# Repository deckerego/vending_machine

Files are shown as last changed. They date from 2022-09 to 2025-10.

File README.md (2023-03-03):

# The Life-Sized Vending Machine

A seven-foot tall Halloween vending machine, inspired by the [Exploding Kittens merch booth](https://makezine.com/article/maker-news/exploding-kittens-vending-machine/).

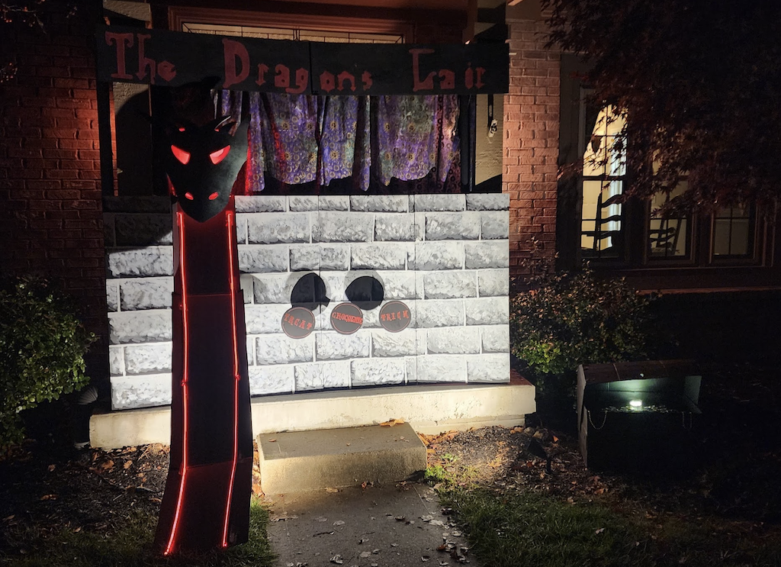
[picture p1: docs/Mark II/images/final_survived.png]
The Mark II Vending machine at night


Mark II Images: [docs/Mark II](docs/Mark%20II/README.md)

Mark II Sketches: [docs/Mark II](docs/Mark%20II/Sketches%20and%20Notes.pdf)

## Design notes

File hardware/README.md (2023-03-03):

# 3D Printed Hardware & Mounts

3D printed hardware used to construct things. Also [available on Printibles](https://www.printables.com/model/414187-dowel-rod-guides-and-mounts)

Included the original Blender source if things need to be scaled.

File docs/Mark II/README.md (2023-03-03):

# Halloween Vending Machine

## Mark II

A brief outline:

Painting the front panels 

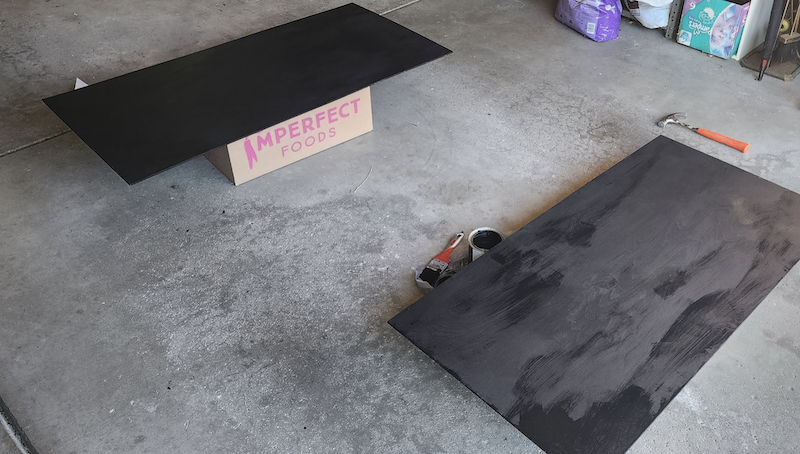
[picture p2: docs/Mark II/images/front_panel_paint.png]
Plywood being painted black for the front of the vending machine


Marking and placing the dowel rod mounts 

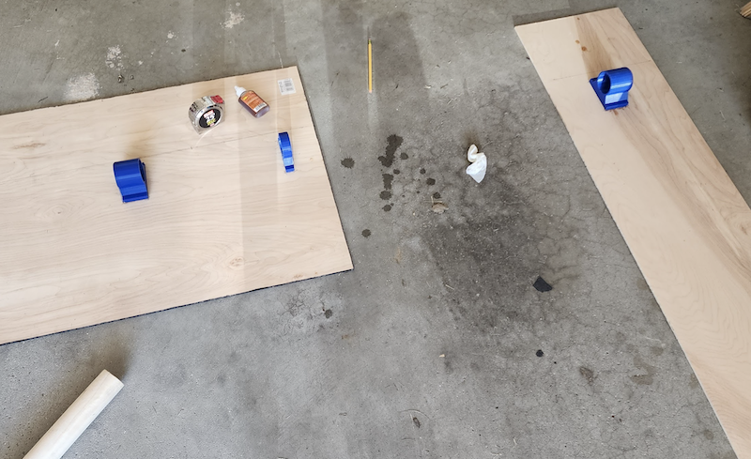
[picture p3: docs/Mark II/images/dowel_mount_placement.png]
Plastic anchors used to hold dowel rolds in place being measured on the back of plywood


Gluing & screwing on the dowel rod mounts 

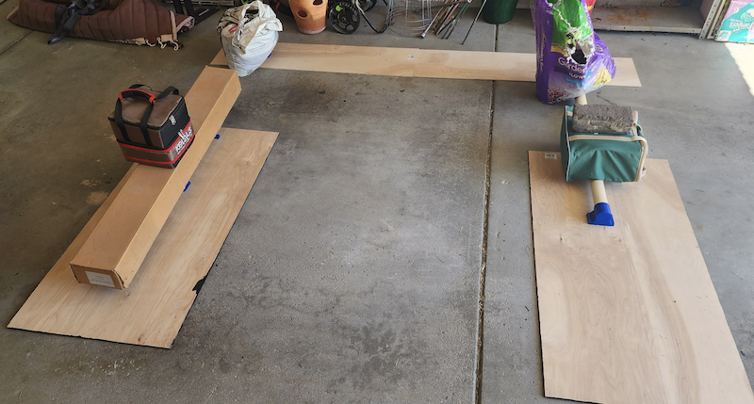
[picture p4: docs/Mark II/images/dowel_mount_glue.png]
Glue setting on plastic dowel rod mounts


Adding hinges to the front panels to make them a larger, foldable structure 

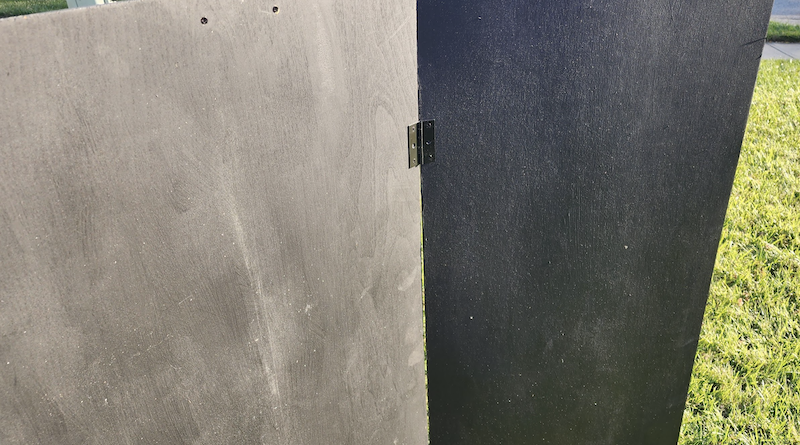
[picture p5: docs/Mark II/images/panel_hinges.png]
Close-up of hinges holding together two plywood sheets
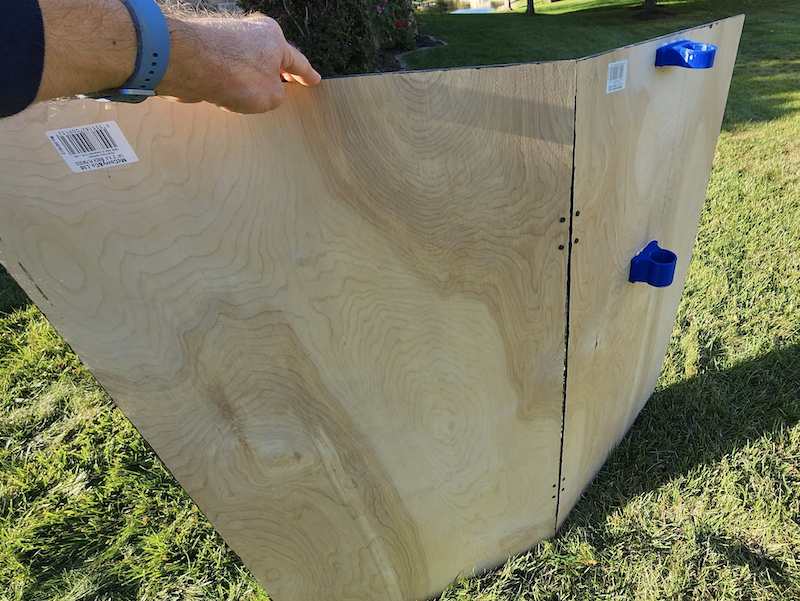
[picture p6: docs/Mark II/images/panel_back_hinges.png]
Opposite side of plywood showing hinges mounting two pieces together
 

Test assembly of the panels, dowel rods, and overhead sign 

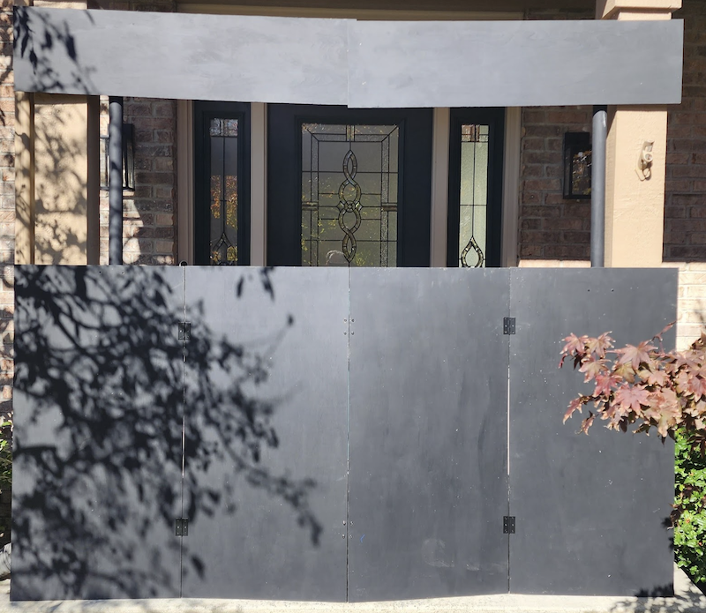
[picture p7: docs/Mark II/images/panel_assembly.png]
The first prototype of the vending machine with working hinges and mounts


1. Paint details & designs on the front panels & signs 

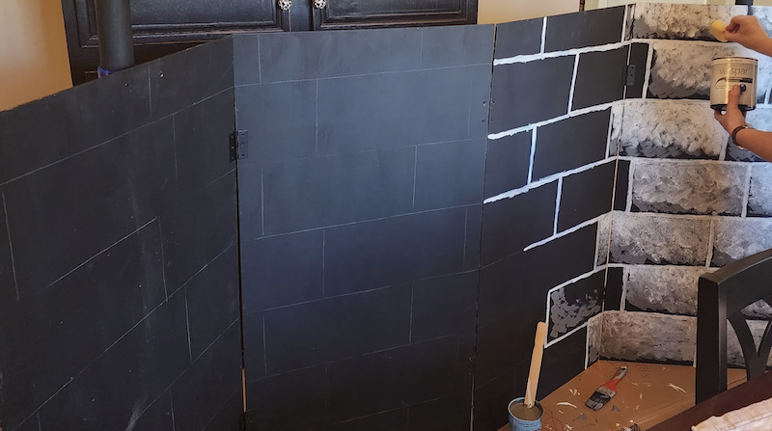
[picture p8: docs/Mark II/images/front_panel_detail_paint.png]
Sponge painting a brick pattern on the front panel


1. Paint buttons and text for buttons 

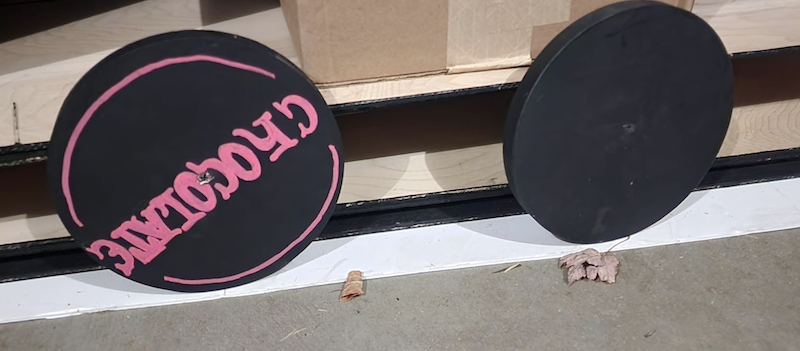
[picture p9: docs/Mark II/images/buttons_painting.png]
Big wooden buttons, one of which says "chocolate."


1. Template, cut, curve, and heat mold the dragon head out of EVA foam 

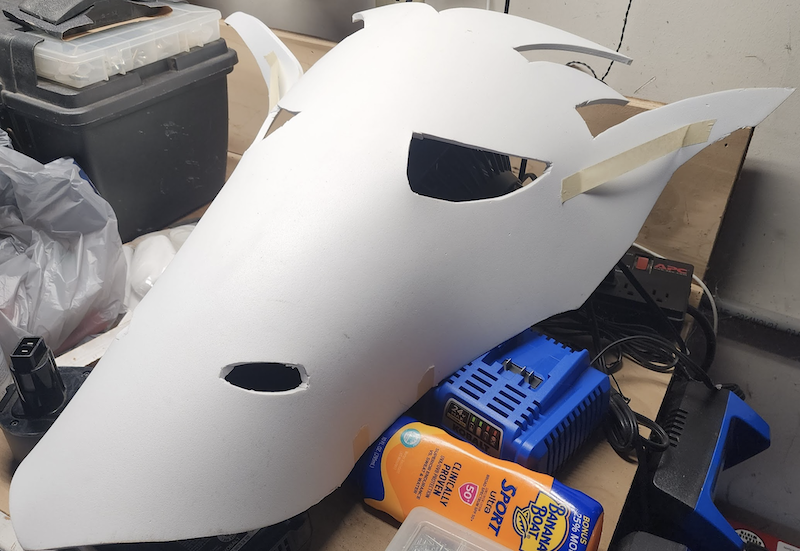
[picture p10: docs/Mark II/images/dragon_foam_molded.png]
A two-dimensional dragon's head made out of foam, held into a shape with tape


1. Prime and paint the dragon's head 

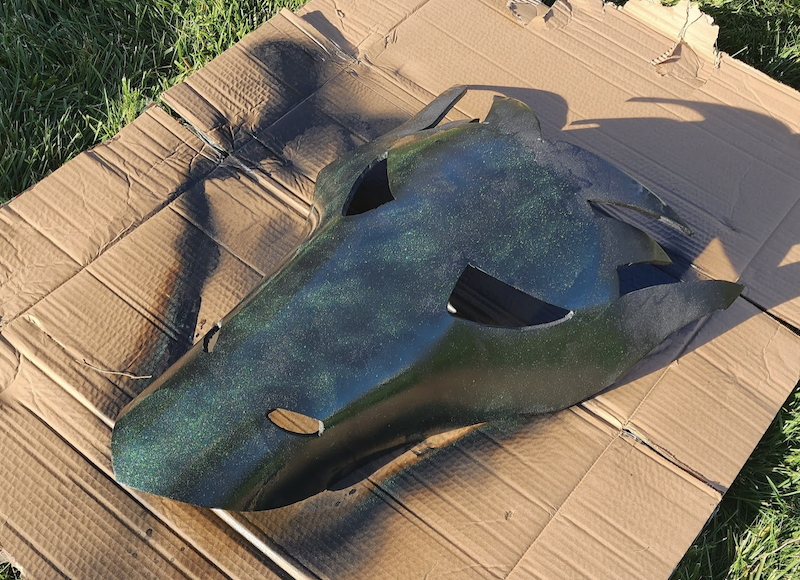
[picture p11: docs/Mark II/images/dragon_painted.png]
The dragon's head from the earlier step spray-painted a glossy green


1. Code an Adafruit Express as an LED backlight for the dragon's head 

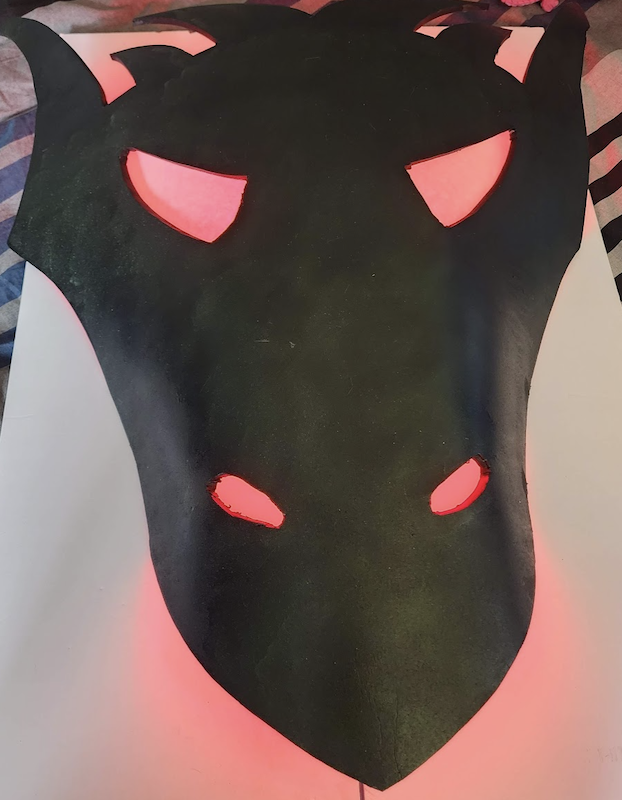
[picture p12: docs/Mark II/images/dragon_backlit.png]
A bright red backlight shines behind the dragon's head


1. Solder jumper wires to the LED strips for the candy ramp 

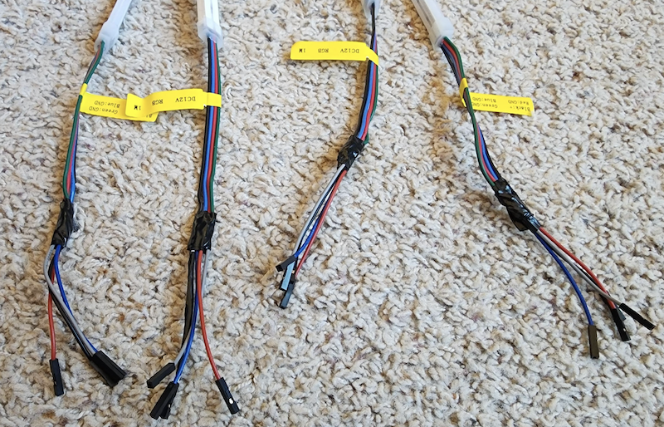
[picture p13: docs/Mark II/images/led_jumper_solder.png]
Jumper wires freshly soldered onto LED ropes


1. Connect buttons, a battery pack, and LED strips to an Arduino. Code to make a fade effect for lighting. 

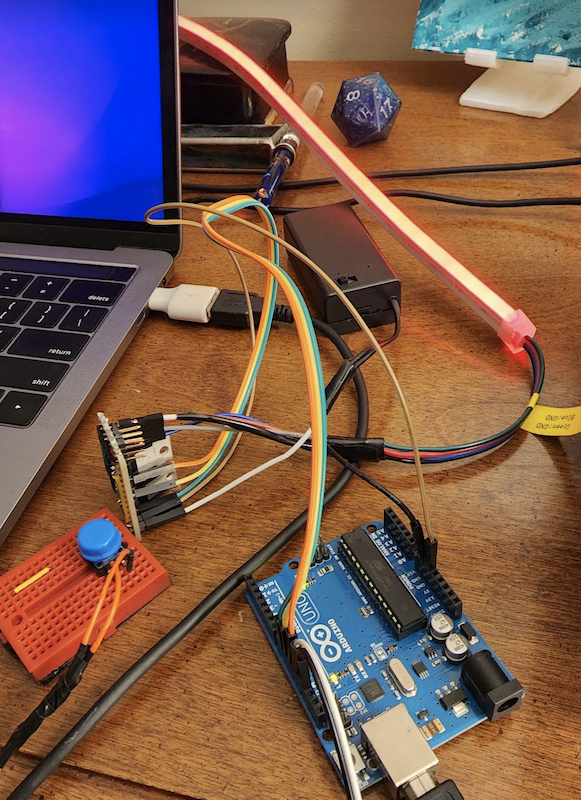
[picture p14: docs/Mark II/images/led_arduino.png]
A mess of wires leading to an Arduino, code showing on a nearby laptop


1. Pull the LED strips through the candy ramp, adhere to the sides. Attach Arduino and battery pack underneath the ramp 

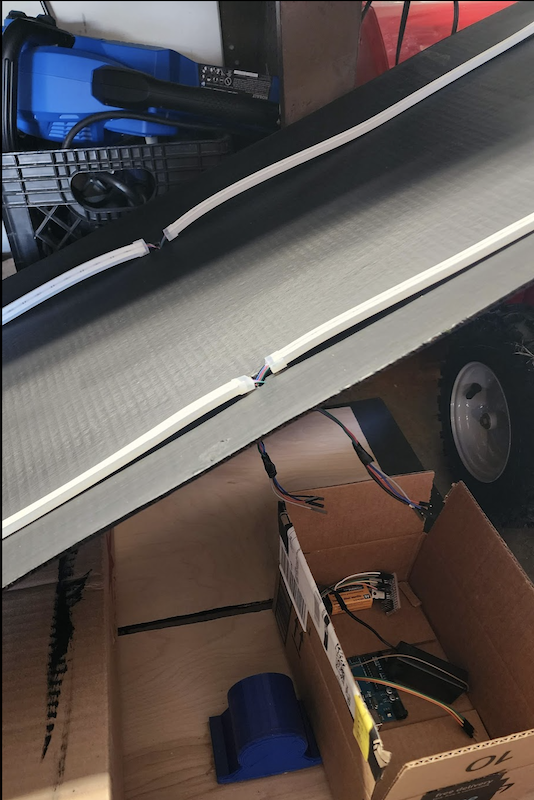
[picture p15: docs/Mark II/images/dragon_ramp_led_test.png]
A prototype candy ramp with LED strips on either side, wires leading to the Arduino assembly


1. Drill holes & mount the button guides within the front panels 

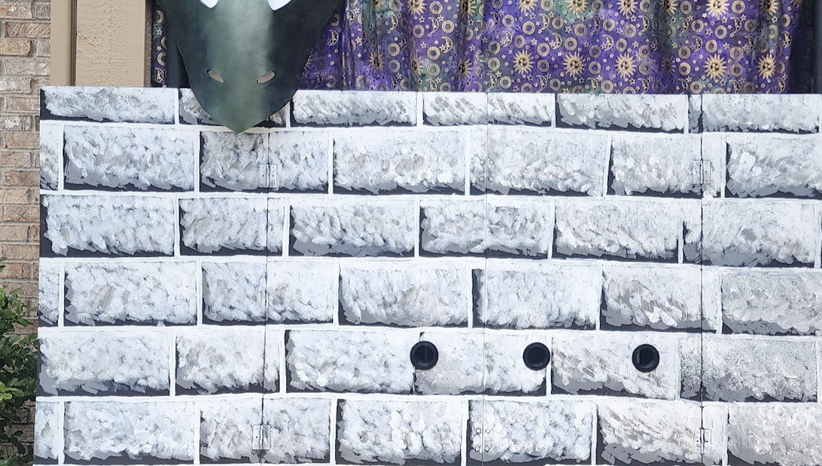
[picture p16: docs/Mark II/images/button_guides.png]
Plastic guides for the button dowel rods inserted into the vending machine panels


1. Anchor entire assembly to front porch 

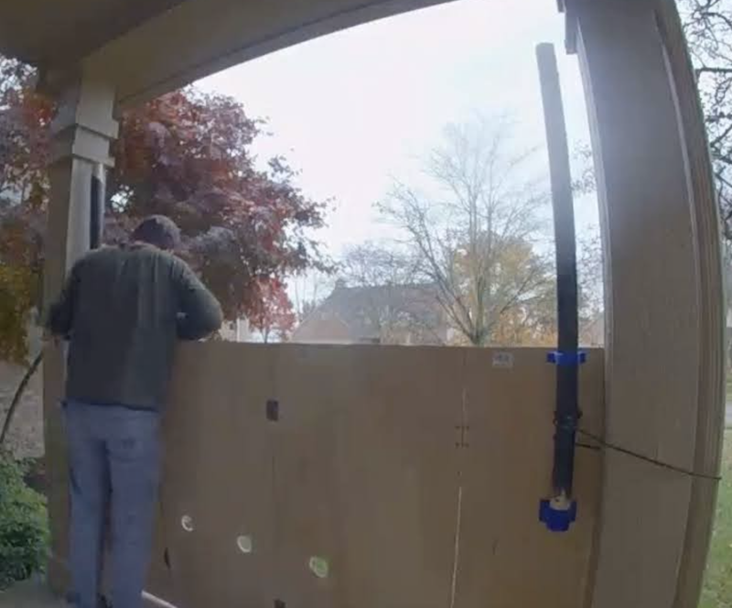
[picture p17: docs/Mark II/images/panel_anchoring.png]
Vending machine being anchored to a front porch using bungee cords


1. Anchor dragon head, candy ramp, insert buttons, add lighting accents 

The whole vending machine assembled with a candy ramp coming from a dragon head, and huge buttons labelled "trick," "treat," and "chocolate"

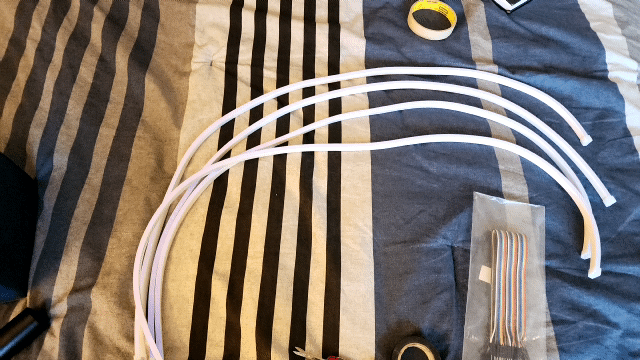
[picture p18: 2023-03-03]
docs/Mark II/images/led_strip_anim.gif

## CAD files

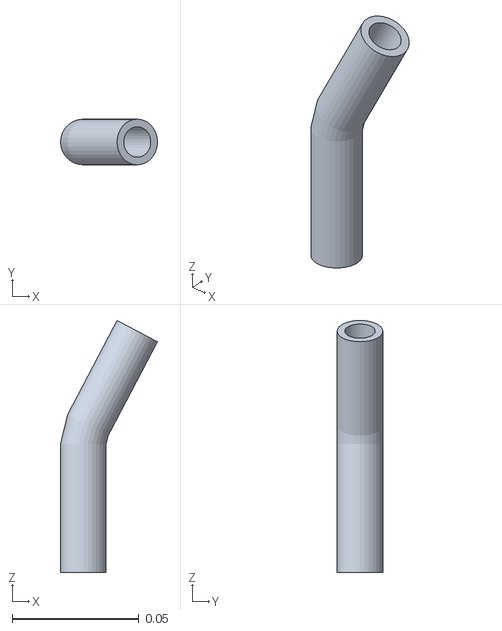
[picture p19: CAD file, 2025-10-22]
hardware/Bend Joint.stl
0.0383 x 0.0181 x 0.0995

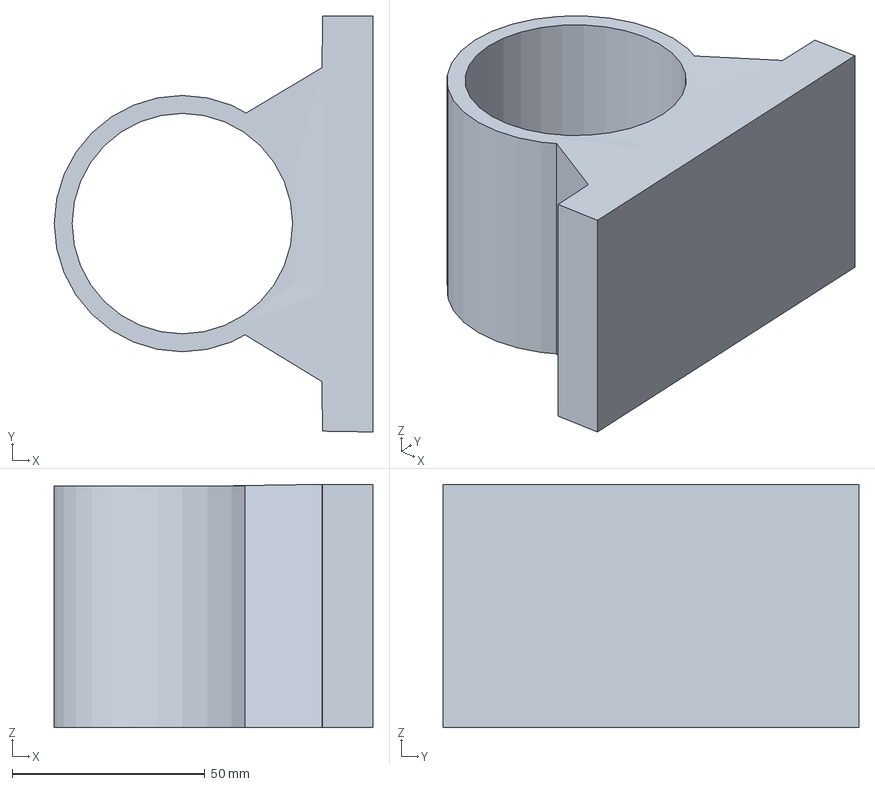
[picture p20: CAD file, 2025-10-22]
hardware/Dowel Rod Guide.3mf
82.6 x 107.9 x 63.1 mm

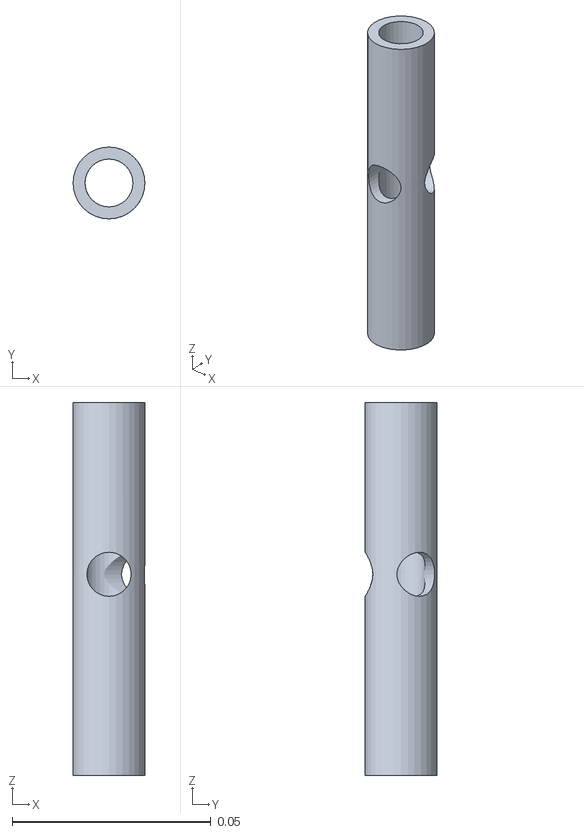
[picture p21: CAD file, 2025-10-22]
hardware/Straight Joint.stl
0.0181 x 0.0181 x 0.0938

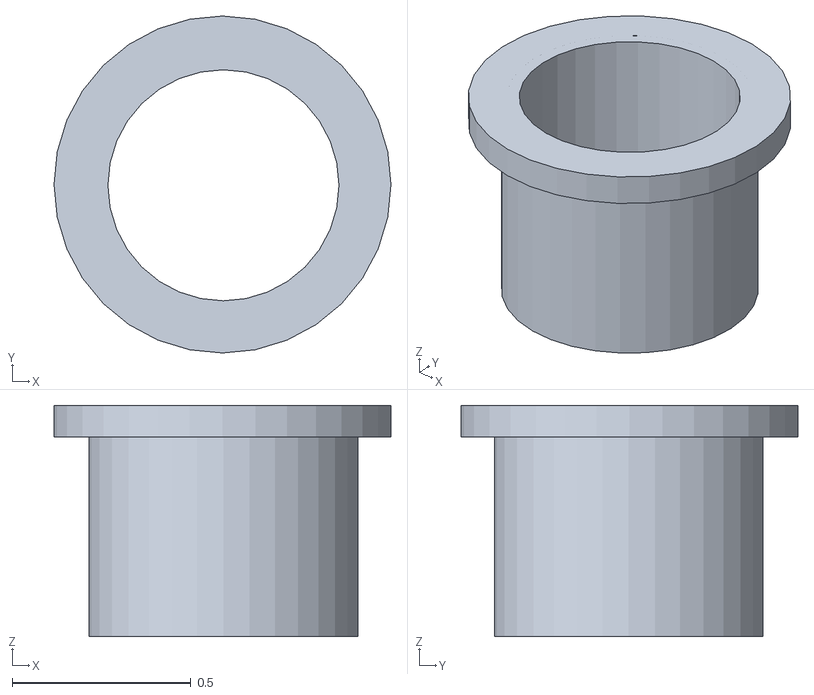
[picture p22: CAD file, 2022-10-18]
hardware/Button Guide.stl
0.944 x 0.944 x 0.648

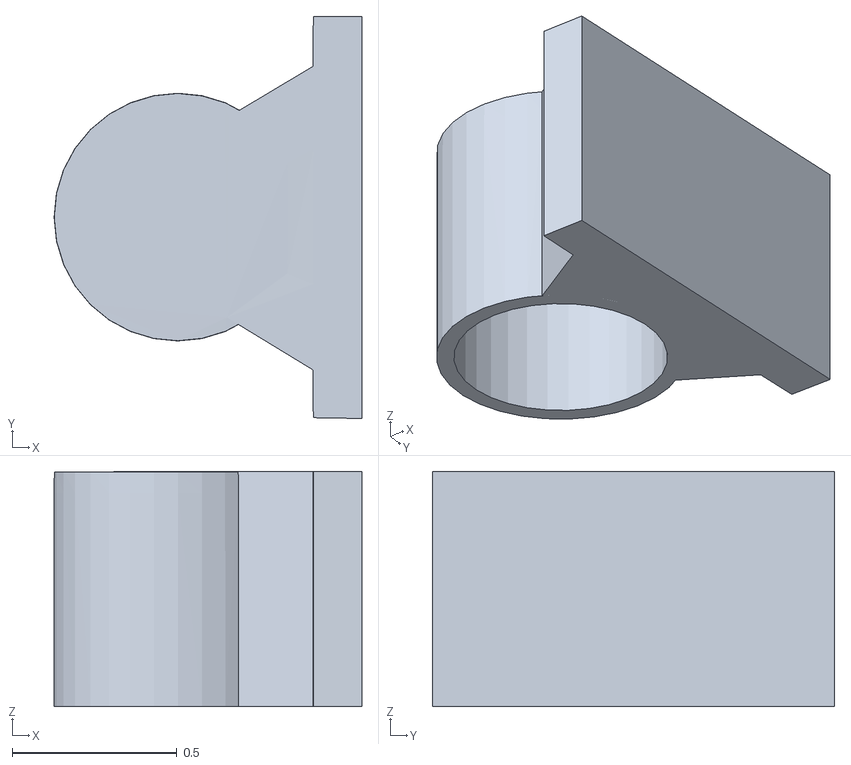
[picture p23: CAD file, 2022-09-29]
hardware/Dowel Rod Mount.stl
0.935 x 1.22 x 0.714

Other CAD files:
hardware/Bend Joint.blend
hardware/Button Guide.blend
hardware/Dowel Rod Guide.blend
hardware/Dowel Rod Guide.stl
hardware/Dowel Rod Mount (Objects).blend
hardware/Dowel Rod Mount.blend
hardware/Straight Joint.blend

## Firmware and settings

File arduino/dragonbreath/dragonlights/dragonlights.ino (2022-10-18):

#define GREENPIN  9
#define BLUEPIN   10
#define REDPIN    11
#define BUTTON    12

int buttonState = 0;

void setup() {
  pinMode(GREENPIN, OUTPUT);
  pinMode(BLUEPIN, OUTPUT);
  pinMode(REDPIN, OUTPUT);
  pinMode(LED_BUILTIN, OUTPUT);
  pinMode(BUTTON, INPUT_PULLUP);

  analogWrite(GREENPIN, 0);
  analogWrite(BLUEPIN, 0);
  analogWrite(REDPIN, 0);
}

void loop() {
  if(digitalRead(BUTTON) == LOW) {
    digitalWrite(LED_BUILTIN, HIGH);
    for (int i = 0; i <= 255; i += 16) {
      analogWrite(REDPIN, i);
      analogWrite(BLUEPIN, i / 2);
      analogWrite(GREENPIN, i / 2);
      delay(100);
    }

    for (int i = 255; i >= 0; i -= 8) {
      analogWrite(REDPIN, 255);
      analogWrite(BLUEPIN, i / 2);
      analogWrite(GREENPIN, i / 2);
      delay(100);
    }

    delay(5000);

    for (int i = 255; i >= 0; i -= 8) {
      analogWrite(REDPIN, i);
      delay(100);
    }

    analogWrite(GREENPIN, 0);
    analogWrite(BLUEPIN, 0);
    analogWrite(REDPIN, 0);
  }
  digitalWrite(LED_BUILTIN, LOW);
}

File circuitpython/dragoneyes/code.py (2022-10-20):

import board
import simpleio
import time
import math
import random
import adafruit_lis3dh
from busio import I2C
from analogio import AnalogIn
from digitalio import DigitalInOut, Direction, Pull
from neopixel import NeoPixel

# NeoPixels
pixels = NeoPixel(board.NEOPIXEL, 10, brightness=1.0, auto_write=False)

# Toggle Switch
switch = DigitalInOut(board.SLIDE_SWITCH)
switch.direction = Direction.INPUT
switch.pull = Pull.UP
switch_state = switch.value

# Button A
button_a = DigitalInOut(board.BUTTON_A)
button_a.direction = Direction.INPUT
button_a.pull = Pull.DOWN
button_a_state = False

# Button B
button_b = DigitalInOut(board.BUTTON_B)
button_b.direction = Direction.INPUT
button_b.pull = Pull.DOWN
button_b_state = False

def event_sleep(seconds):
    check_inputs()
    time.sleep(seconds)

def check_inputs():
    global switch_state, button_a_state, button_b_state

    if button_b.value is not button_b_state:
        button_b_state = button_b.value
        if button_b_state: press_b()
    if switch.value is not switch_state:
        switch_state = switch.value
        flip_switch()

def press_b():
    global shader_index
    shader_index = (shader_index + 1) % len(SHADERS)

def flip_switch():
    global power

    if switch_state:
        power = True
    else:
        if power:
            power = False
            pixels.fill((0, 0, 0))
            pixels.brightness = 0.0
            pixels.show()

def show_timer(shader):
    for frame in range(20):
        frame_sleep = shader(frame)
        pixels.show()
        event_sleep(frame_sleep)

def shader_breathe(frame):
    color = (255, 0, 0)
    idx = frame if frame < 10 else frame - ((frame - 10) << 1)
    gamma = LOG_10[idx]

    for pixel in range(10):
        pixels[pixel] = list(map(lambda c: math.ceil(gamma * c), color))

    if(gamma == 1.0): return random.randrange(1, 50, 1) / 10
    elif(gamma == 0.0): return 2.0
    else: return 0.2

def shader_sparkle(frame):
    for pixel in range(10):
        gamma_palette = round(random.random(), 2) / 3, round(random.random(), 2), 1.0
        color = 15 + ((pixel & 3) * 80)
        pixels[random.randrange(10)] = list(map(lambda g: math.ceil(color * g), gamma_palette))
    return 0.05

def shader_rainbow(frame):
    for pixel in range(10):
        color = (0, 0, 0)
        base = (pixel % 3) * 60
        if pixel <= 2 or pixel == 9: color = (100 - int(base / 2), base, 0)
        elif pixel <= 5: color = (0, 200 - base, base)
        else: color = (base, 0, 200 - base)
        pixels[(pixel + frame) % 10] = color
    return 0.05

# Constants
LOG_10 = [0.0, 0.3010, 0.4771, 0.6021, 0.6990, 0.7782, 0.8451, 0.9031, 0.9542, 1.0, 1.0]
SHADERS = [ shader_breathe, shader_sparkle, shader_rainbow ]

# Default state
power = switch_state
last_time_seconds = time.time()
shader_index = 0

while True:
    if power:
        pixels.brightness = 1.0
        show_timer(SHADERS[shader_index])
    else:
        event_sleep(1.0)

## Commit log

2022-09-29 Added in 3D printable mounts
    [Dowel Rod Guide.blend, Dowel Rod Guide.stl, Dowel Rod Mount (Objects).blend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]
2022-09-30 Added demo code for Arduino
2022-10-17 Added button guide hardware
    [Button Guide.blend, Button Guide.stl]
2022-10-18 Flattened out button guide, closed open faces
    [Button Guide.blend, Button Guide.stl]
2022-10-18 Flame animation on button press
2022-10-18 Another attempting at a cleaner build
    [Button Guide.blend, Button Guide.stl]
2022-10-18 Re-do the button guide - STL kept getting corrupted
    [Button Guide.blend, Button Guide.stl]
2022-10-18 Final version of button guide, printed at 83% scale
    [Button Guide.blend, Button Guide.stl]
2022-10-20 Fixed brightness for dragon eyes
    [code.py]
2023-10-17 First draft of joint for creating a chute out of gardening stakes
    [Stake Joint.blend, Stake Joint.stl]
2024-10-30 Updated to latest Arduino IDE
2025-10-22 Added new joint type for chute
    [Bend Joint.blend, Bend Joint.stl, Dowel Rod Guide.3mf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]
